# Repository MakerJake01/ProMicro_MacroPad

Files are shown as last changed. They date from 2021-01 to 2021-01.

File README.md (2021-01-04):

# ProMicro_MacroPad

**Overview** <br>
This project is for anyone who wants to make an 8 key MacroPad. The parts will most likely cost more than buying one. It can be used for keybinds in many programs. 
It's perfect for switching between scenes in OBS or a mute/unmute button in Discord. Some of the code is probably not the most efficient as I am a beginner. I am looking into making it work with QMK. 

<blockquote class="imgur-embed-pub" lang="en" data-id="a/6hcVxPT"  ><a href="//imgur.com/a/6hcVxPT">MacroPad pics</a></blockquote>

**The programing:** <br>
The code was all programmed in C++ using the Arduino IDE. It can be programmed with F keys (i.e. F13, F14, ...).
It uses the [keyboard.h](https://www.arduino.cc/reference/en/language/functions/usb/keyboard/) library. I have tried to make it as easy to reprogram as possible. 
It may be possible to program the MacroPad more efficiently. 

**The soldering:** <br>
There is a lot of SMD soldering. The smallest parts are 1206 resistors and capacitors. Some of the pads for the LEDs on the back do get very close. It will be an intermediate to advanced soldering project. (I have been soldering for a while so, SMD soldering is easy for me.) [SMD Soldering Guide](https://www.youtube.com/watch?v=VxMV6wGS3NY&t=544s)

**The PCB:** <br>
Use the Gerber files to make the PCBs. It's a two-layer PCB and a 1.6 mm board. A black solder mask will look better but will add some time and possible cost.  

**The switches** <br>
The PCB has the holes for an MX style switch. The PCB has the holes for a plate mount switch. If you have a PCB mount switch, the extra legs need to be cut off.

**Build guide** <br>
I am working on a multi-part build guide for my youtube channel.  
https://www.youtube.com/makerjake

**printed parts** <br>
I am having some trouble finding the STL files and my fusion 360 subscriptions has run out. I will try to either redesign the parts of finding the files. 

Creative Commons Attribution-NonCommercial 4.0 International License. cc-by-nc

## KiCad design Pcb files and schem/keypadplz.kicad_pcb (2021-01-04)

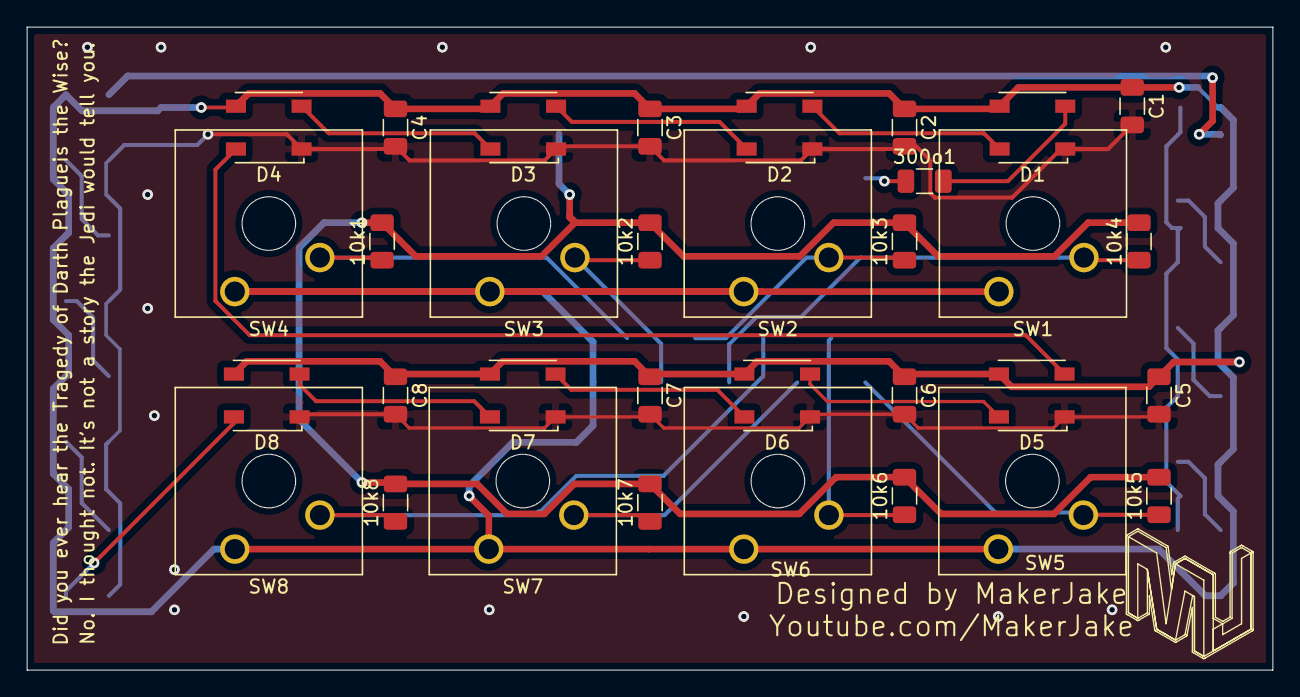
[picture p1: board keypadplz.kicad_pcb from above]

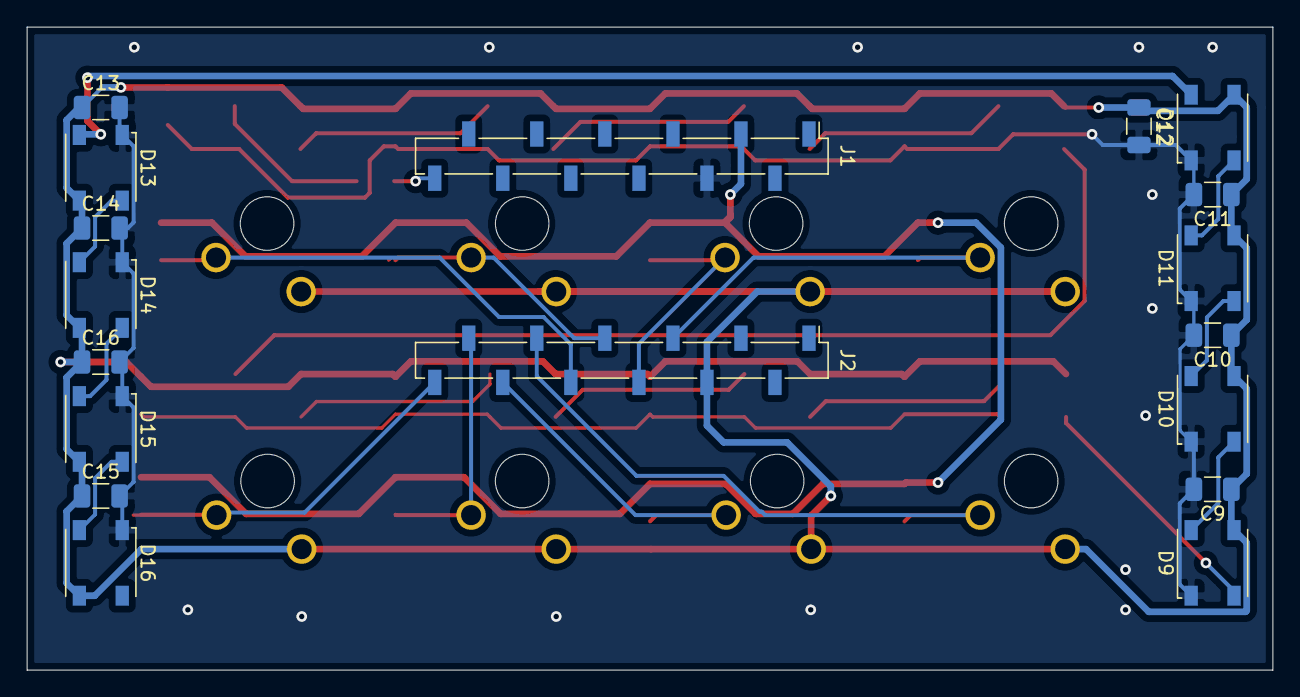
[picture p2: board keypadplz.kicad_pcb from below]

Board: 2 copper layers, 93.0 x 48.0 mm, 51 parts (18 on the bottom side), 28 nets.

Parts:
10k1, 10k2, 10k3, 10k4, 10k5, 10k6, 10k7, 10k8: R1; R_1206_3216Metric
300o1: R; R_1206_3216Metric
C1, C2, C3, C4, C5, C6, C7, C8, C9, C10, C11, C12, C13, C14, C15, C16: C_Small; C_1206_3216Metric
D1, D2, D3, D4, D5, D6, D7, D8, D9, D10, D11, D12, D13, D14, D15, D16: Inolux_IN-PI554FCH; LED_Inolux_IN-PI554FCH_PLCC4_5.0x5.0mm_P3.2mm
J1, J2: Conn_01x12_Male; PinSocket_1x12_P2.54mm_Vertical_SMD_Pin1Left
SW1, SW2, SW3, SW4, SW5, SW6, SW7, SW8: SW_Push; SW_Cherry_MX_1.00u_Plate

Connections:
GND: C1.2, C2.2, C3.2, C4.2, C5.2, C6.2, C7.2, C8.2, C9.2, C10.2, C11.2, C12.2, C13.2, C14.2, C15.2, C16.2, D1.1, D2.1, D3.1, D4.1, D5.1, D6.1, D7.1, D8.1, D9.1, D10.1, D11.1, D12.1, D13.1, D14.1, D15.1, D16.1, J1.4
unnamed: 10k1.1, J2.5, SW4.2
unnamed: 10k1.2, 10k2.2, 10k3.2, 10k4.2, 10k5.2, 10k6.2, 10k7.2, 10k8.2, J1.3
unnamed: 10k2.1, J2.6, SW3.2
unnamed: 10k3.1, J2.7, SW2.2
unnamed: 10k4.1, J2.8, SW1.2
unnamed: 10k5.1, J2.12, SW5.2
unnamed: 10k6.1, J2.11, SW6.2
unnamed: 10k7.1, J2.10, SW7.2
unnamed: 10k8.1, J2.9, SW8.2
unnamed: 300o1.1, J1.12
unnamed: 300o1.2, D1.2
unnamed: C1.1, C2.1, C3.1, C4.1, C5.1, C6.1, C7.1, C8.1, C9.1, C10.1, C11.1, C12.1, C13.1, C14.1, C15.1, C16.1, D1.3, D2.3, D3.3, D4.3, D5.3, D6.3, D7.3, D8.3, D9.3, D10.3, D11.3, D12.3, D13.3, D14.3, D15.3, D16.3, J2.4, SW1.1, SW2.1, SW3.1, SW4.1, SW5.1, SW6.1, SW7.1, SW8.1
unnamed: D1.4, D2.2
unnamed: D2.4, D3.2
unnamed: D3.4, D4.2
unnamed: D4.4, D5.2
unnamed: D5.4, D6.2
unnamed: D6.4, D7.2
unnamed: D7.4, D8.2
unnamed: D8.4, D9.2
unnamed: D9.4, D10.2
unnamed: D10.4, D11.2
unnamed: D11.4, D12.2
unnamed: D12.4, D13.2
unnamed: D13.4, D14.2
unnamed: D14.4, D15.2
unnamed: D15.4, D16.2

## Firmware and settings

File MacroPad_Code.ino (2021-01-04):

//libs
#include <Keyboard.h>
#include <Adafruit_NeoPixel.h>

//neo-pixel setup
#define PIN        9
#define NUMPIXELS  16
Adafruit_NeoPixel pixels = Adafruit_NeoPixel(NUMPIXELS, PIN, NEO_GRB + NEO_KHZ800);

//Time till light turns off after push
int delayval = 25;
//extra time for the function keys
int delA = 150;

//switches and text
int but8 = 0;
const int but8pin = 10; 
const char *mess8 = "Put Text Here";

int but7 = 0;
const int but7pin = 16;
const char *mess7 = "Put Text Here #2";


int but6 = 0;
const int but6pin = 14;
const char *mess6 = "Put Text Here #3";

int but5 = 0;
const int but5pin = 15;
const char *mess5 = "Put Text Here #4";

int but4 = 0;
const int but4pin = A0;

int but3 = 0;
const int but3pin = A1;

int but2 = 0;
const int but2pin = A2;

int but1 = 0;
const int but1pin = A3;

int muteTog = 0;

//Colors
uint32_t on = pixels.Color(255, 0, 255);

uint32_t base0  = pixels.Color(78,  202, 230);
uint32_t base1  = pixels.Color(171, 243, 114);
uint32_t base2  = pixels.Color(255, 241,  42);
uint32_t base3  = pixels.Color(255, 154, 116);
uint32_t base4  = pixels.Color(176, 150, 255);
uint32_t base5  = pixels.Color(80,  204, 225);
uint32_t base6  = pixels.Color(173, 244, 111);
uint32_t base7  = pixels.Color(252, 245,  42);
uint32_t base8  = pixels.Color(255, 186,  84);
uint32_t base9  = pixels.Color(255, 147, 123);
uint32_t base10 = pixels.Color(255, 119, 152);
uint32_t base11 = pixels.Color(255, 74,  198);
uint32_t base12 = pixels.Color(65,  167, 255);
uint32_t base13 = pixels.Color(84,  141, 255);
uint32_t base14 = pixels.Color(123, 103, 255);
uint32_t base15 = pixels.Color(140, 88,  255);

/*

*/

void setup() {
  // put your setup code here, to run once:
  
  //pin declaration
  pinMode(but8pin, INPUT);
  pinMode(but7pin, INPUT);
  pinMode(but6pin, INPUT);
  pinMode(but5pin, INPUT);
  pinMode(but4pin, INPUT);
  pinMode(but3pin, INPUT);
  pinMode(but2pin, INPUT);
  pinMode(but1pin, INPUT);

  Keyboard.begin(); //Init keyboard emulation

  //neopixels started
  pixels.begin();
  pixels.setBrightness(75);

  pixels.setPixelColor(0, base0);
  pixels.setPixelColor(1, base1);
  pixels.setPixelColor(2, base2);
  pixels.setPixelColor(3, base3);
  pixels.setPixelColor(4, base4);
  pixels.setPixelColor(5, base5);
  pixels.setPixelColor(6, base6);
  pixels.setPixelColor(7, base7);
  pixels.setPixelColor(8, base8);
  pixels.setPixelColor(9, base9);
  pixels.setPixelColor(10, base10);
  pixels.setPixelColor(11, base11);
  pixels.setPixelColor(12, base12);
  pixels.setPixelColor(13, base13);
  pixels.setPixelColor(14, base14);
  pixels.setPixelColor(15, base15);
  pixels.show();

}

void loop() {
  // put your main code here, to run repeatedly:

  //start reading inputs
  but8 = digitalRead(but8pin);
  but7 = digitalRead(but7pin);
  but6 = digitalRead(but6pin);
  but5 = digitalRead(but5pin);
  but4 = digitalRead(but4pin);
  but3 = digitalRead(but3pin);
  but2 = digitalRead(but2pin);
  but1 = digitalRead(but1pin);

  //switch 8
  if (but8 == HIGH) {
    pixels.setPixelColor(4, on);
    pixels.show();
    Keyboard.write(' ');
    for (int mess8idx = 0; mess8idx < strlen(mess8); mess8idx++) {
      Keyboard.write(mess8[mess8idx]);
    }
    Keyboard.releaseAll();
    Keyboard.write(' ');
    delay(delayval);
    pixels.setPixelColor(4, base4);
    pixels.show();
  }

  //switch 7
  if (but7 == HIGH) {
    pixels.setPixelColor(5, on);
    pixels.show();
    Keyboard.write(' ');
    for (int mess7idx = 0; mess7idx < strlen(mess7); mess7idx++) {
      Keyboard.write(mess7[mess7idx]);
    }
    Keyboard.write(' ');
    delay(delayval);
    pixels.setPixelColor(5, base5);
    pixels.show();
  }

  //switch 6
  
  if (but6 == HIGH) {
    pixels.setPixelColor(6, on);
    pixels.show();
    Keyboard.write(' ');
     for(int mess6idx = 0; mess6idx < strlen(mess6); mess6idx++){
      Keyboard.write(mess6[mess6idx]);
    }
    Keyboard.write(' ');
    delay(delayval);
    pixels.setPixelColor(6, base6);
    pixels.show();
  }

  //switch 5
  if(but5 == HIGH){
    pixels.setPixelColor(7,on);
    pixels.show();
    Keyboard.write(' ');
    for(int mess5idx = 0; mess5idx < strlen(mess5); mess5idx++){
      Keyboard.write(mess5[mess5idx]);
    }
    Keyboard.write(' ');
    delay(delayval);
    pixels.setPixelColor(7,base7);
    pixels.show();
  }

  //switch 4
  if (but4 == HIGH) {
    pixels.setPixelColor(0, on);
    pixels.show();
    Keyboard.press(KEY_F18);
    delay(delayval + delA);
    Keyboard.releaseAll();
    pixels.setPixelColor(0, base0);
    pixels.show();
  }

  //switch 3
  if (but3 == HIGH) {
    pixels.setPixelColor(1, on);
    pixels.show();
    Keyboard.press(KEY_F18);
    delay(delayval + delA);
    Keyboard.releaseAll();
    pixels.setPixelColor(1, base1);
    pixels.show();
  }

  //switch 2
  if (but2 == HIGH) {
    pixels.setPixelColor(2, on);
    pixels.show();
    Keyboard.press(KEY_F17);
    delay(delayval + delA);
    Keyboard.releaseAll();
    pixels.setPixelColor(2, base2);
    pixels.show();
  }

  //switch 1
  if (but1 == HIGH) {
    pixels.setPixelColor(3, on);
    pixels.show();
    Keyboard.press(KEY_F16);
    delay(delayval + delA);
    Keyboard.releaseAll();
    pixels.setPixelColor(3, base3);
    pixels.show();
  }

  /*
  If you use the macropad to mute/unmute you might want the led color to reflect its state. This code should do that. 
  If you set this for many switches then you should add more "int muteTog = 0;" statements. But add numbers on the end, for example, muteTog1. 
  also, change the pins in the example code to the pins on the actual switch.
  
  if (but2 == HIGH) {
    if (muteTog == 0) {
      pixels.setPixelColor(2, on);
      muteTog = 1;
      pixels.show();
    } else if (muteTog == 1) {
      pixels.setPixelColor(2, base2);
      muteTog = 0;
      pixels.show();
    }
    Keyboard.press(KEY_F14);
    delay(delayval + delA);
    Keyboard.releaseAll();
    
  }
  */

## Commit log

2020-08-17 Add files via upload
    These files are used in the production of the PCB.
2021-01-04 added the KiCad files and pcb files
    [KeyPadV3.kicad_pcb]
